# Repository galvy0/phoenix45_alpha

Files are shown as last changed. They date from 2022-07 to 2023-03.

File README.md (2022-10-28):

# Phoenix45 Alpha Stagger PCB
Alpha stagger version of Phoenix45.  
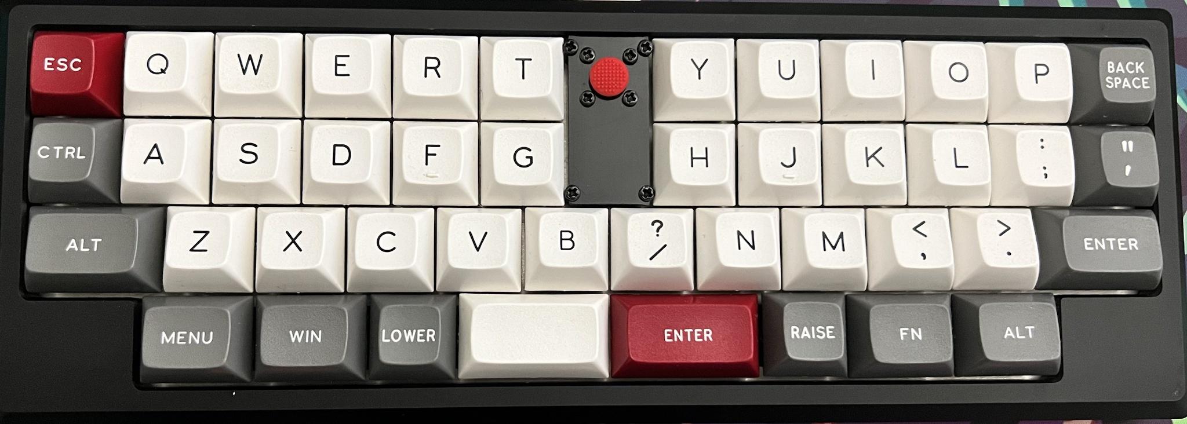
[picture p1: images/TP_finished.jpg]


## PCB
### Layout Options
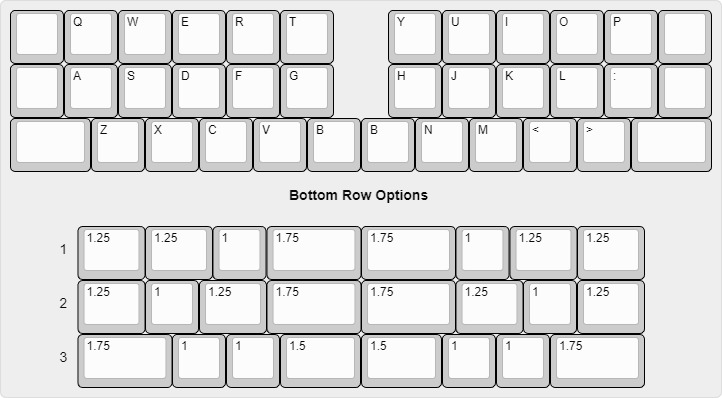
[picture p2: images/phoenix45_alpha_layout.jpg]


## Middle Column Options
The middle column can be configured with either an OLED or a trackpoint module.  

### Middle Column Cover
Either case, I provide the files for a cover along with plate option to mount the cover.  
Using the cover would help fill/cover up the space between the plate and the top of the case and make the middle column look more flush with the top of the case (a.k.a it's just for aesthetics).  
To use the cover, you need M2 screws and standoffs - I find ~6 mm is a good length for the standoffs, though 7 mm also works well and gives enough space for the trackpoint module.  

### Trackpoint module
The only TP module compatible with this is the two-piece module found in ThinkPad T440/T450/T460/T470/T480, P52s, X240, X250, X260 X270 (according to https://deskthority.net/wiki/TrackPoint_Hardware).  
I just bought some replacement T440/T450 keyboards from Ebay and scavanged the TP modules.  
Steps (Very rough - I will try to take some photos for better instructions next time I build this):  
1. Unscrew the casing for the TP module.
2. Install a TP cover. This can be done later.    
Depending on the thickness of the cover, you may want to have hex nuts between the module and the cover so the TP sticks out as little as possible (mainly for aesthetics).  
3. Desolder all the lines and reconnect them using flexible wires so you can readjust the position of the TP module with the TP PCB.  
4. Refer to the pinouts from Deskthority to connect the pins on the TP PCB to the keyboard PCB.  
 
5. With the plate standoffs pre-installed, position the TP PCB slanted through the middle column.  
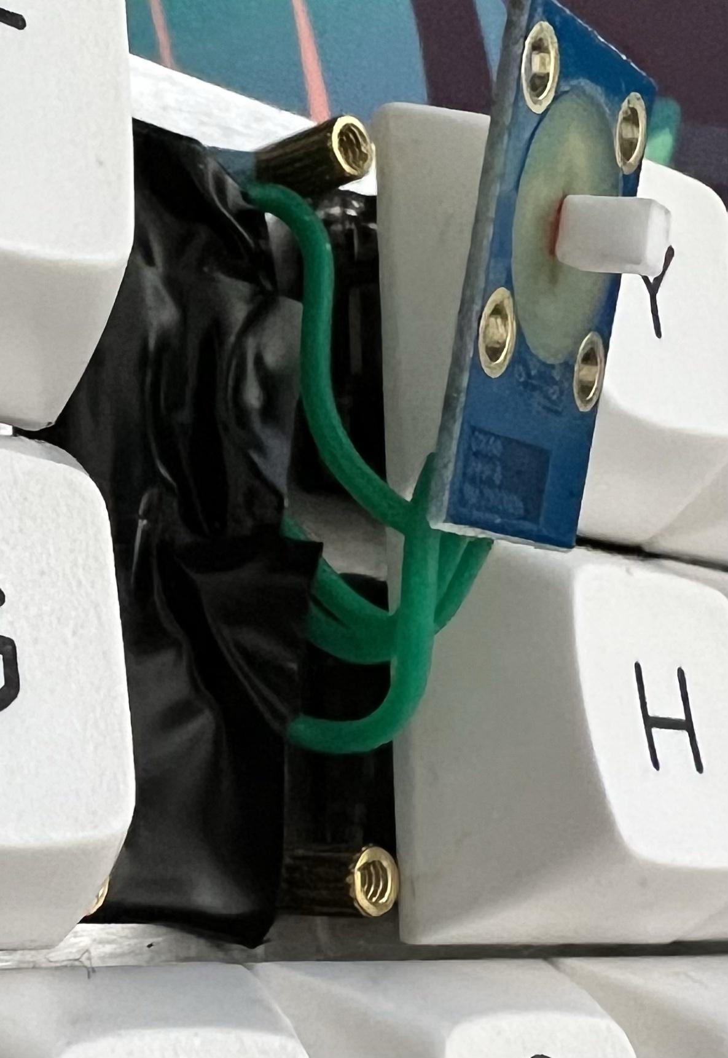
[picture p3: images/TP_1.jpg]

6. Install the TP cover to the plate.  
After all is done, it would look something like this: 
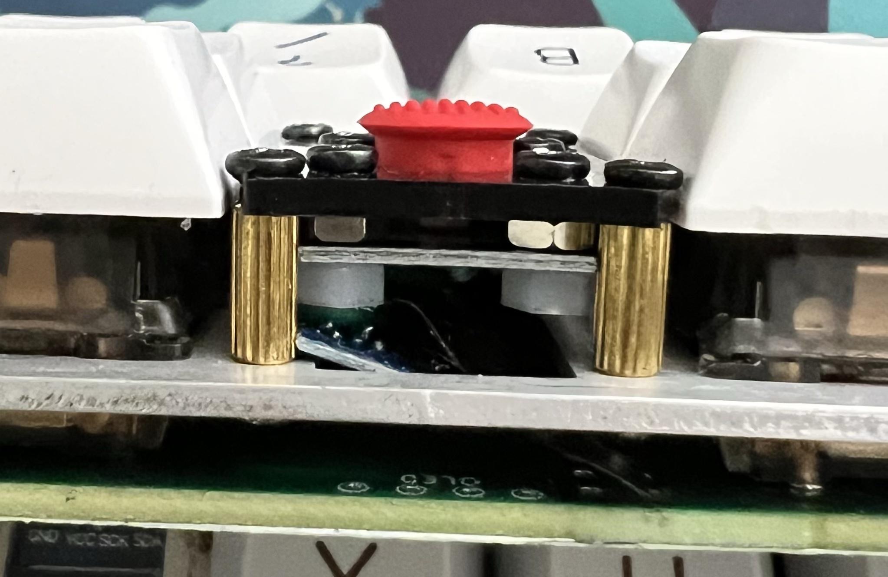
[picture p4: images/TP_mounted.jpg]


## QMK Firmware
https://github.com/galvy0/qmk_firmware/tree/galvy/keyboards/galvy/jd45_alpha

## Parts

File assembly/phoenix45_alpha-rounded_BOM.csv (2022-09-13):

Id | Designator | Package | Quantity | Designation | Supplier and ref
1 | K_SPACE30,K_SPACE31,K_SPACE38,K_SPACE22,K_SPACE11,K_SPACE39,K_SPACE1,K_SPACE46,K_SPACE50,K_SPACE12,K_SPACE10,K_SPACE37,K_SPACE24,K_SPACE9,K_SPACE15,K_SPACE55,K_SPACE51,K_SPACE17,K_SPACE34,K_SPACE41,K_SPACE16,K_SPACE25,K_SPACE59,K_SPACE21,K_SPACE28,K_SPACE35,K_SPACE6,K_SPACE14,K_SPACE54,K_SPACE3,K_SPACE58,K_SPACE19,K_SPACE13,K_SPACE5,K_SPACE26,K_SPACE36,K_SPACE18,K_SPACE8,K_SPACE27,K_SPACE32,K_SPACE29,K_SPACE23,K_SPACE2,K_SPACE4 | MXOnly-1U-NoLED | 44 | KEYSW
2 | K_SPACE40,K_SPACE42,K_SPACE57,K_SPACE33,K_SPACE48,K_SPACE47,K_SPACE45,K_SPACE60 | MXOnly-1.25U-NoLED | 8 | KEYSW
3 | K_SPACE56,K_SPACE49,K_SPACE43,K_SPACE44 | MXOnly-1.75U-NoLED | 4 | KEYSW
4 | SW3 | RotaryEncoder_Alps_EC11E-Switch_Vertical_H20mm | 1 | RotaryEncoder_Switch
5 | SW2,SW1 | SW_SPST_SKQG_WithoutStem | 2 | SW_PUSH
6 | TP1 | TestPoint_THTPad_1.0x1.0mm_Drill0.5mm | 1 | TPCLK
7 | TP3 | TestPoint_THTPad_1.0x1.0mm_Drill0.5mm | 1 | TPGND
8 | TP2 | TestPoint_THTPad_1.0x1.0mm_Drill0.5mm | 1 | TPVCC
9 | TP5 | TestPoint_THTPad_1.0x1.0mm_Drill0.5mm | 1 | TPRST
10 | K_SPACE52,K_SPACE7,K_SPACE20,K_SPACE53 | MXOnly-1.5U-NoLED | 4 | KEYSW
11 | TP4 | TestPoint_THTPad_1.0x1.0mm_Drill0.5mm | 1 | TPDATA
12 | OL1 | OLED_v2 | 1 | OLED
13 | D_SPACE29,D_SPACE30,D_SPACE44,D_SPACE26,D_SPACE22,D_SPACE16,D_SPACE13,D_SPACE43,D_SPACE45,D_SPACE25,D_SPACE28,D_SPACE39,D_SPACE2,D_SPACE14,D_SPACE46,D_SPACE11,D_SPACE4,D_SPACE8,D_SPACE19,D_SPACE42,D_SPACE12,D_SPACE23,D_SPACE34,D_SPACE36,D_SPACE32,D_SPACE3,D_SPACE24,D_SPACE31,D_SPACE37,D_SPACE38,D_SPACE10,D_SPACE6,D_SPACE5,D_SPACE27,D_SPACE41,D_SPACE35,D_SPACE21,D_SPACE18,D_SPACE9,D_SPACE17,D_SPACE15,D_SPACE1,D_SPACE40,D_SPACE47 | D_SOD-123 | 44 | D
14 | UR2,UR1 | R_0805_2012Metric_Pad1.20x1.40mm_HandSolder | 2 | 22
15 | X1 | Crystal_SMD_3225-4Pin_3.2x2.5mm_HandSoldering | 1 | Crystal_GND24_Small
16 | C0 | C_0805_2012Metric_Pad1.18x1.45mm_HandSolder | 1 | 4.7uF
17 | C2,C4,C5,C3 | C_0805_2012Metric_Pad1.18x1.45mm_HandSolder | 4 | 0.1uf
18 | R2,R1 | R_0805_2012Metric_Pad1.20x1.40mm_HandSolder | 2 | 10k
19 | U2 | QFN-44-1EP_7x7mm_P0.5mm_EP5.2x5.2mm_ThermalVias | 1 | ATmega32U4-M
20 | C8,C7 | C_0805_2012Metric_Pad1.18x1.45mm_HandSolder | 2 | 22p
21 | C6 | C_0805_2012Metric_Pad1.18x1.45mm_HandSolder | 1 | 1uf
22 | UR3 | R_0805_2012Metric_Pad1.20x1.40mm_HandSolder | 1 | 1M
23 | C1 | C_0805_2012Metric_Pad1.18x1.45mm_HandSolder | 1 | 10uF
24 | UR4,UR5 | R_0805_2012Metric_Pad1.20x1.40mm_HandSolder | 2 | 5.1k
25 | C9 | C_0805_2012Metric_Pad1.18x1.45mm_HandSolder | 1 | 2.2uF
26 | UR8 | R_0805_2012Metric_Pad1.20x1.40mm_HandSolder | 1 | 100k
27 | USB1 | HRO-TYPE-C-31-M-12-HandSoldering | 1 | HRO-TYPE-C-31-M-12
28 | J1 | IDC-Header_2x03_P2.54mm_Vertical | 1 | AVR-ISP-6
29 | U1 | SOT-23-6_Handsoldering | 1 | SRV05-4
30 | UR7,UR6 | R_0805_2012Metric_Pad1.20x1.40mm_HandSolder | 2 | 4.7k
31 | F1 | Fuse_1206_3216Metric_Pad1.42x1.75mm_HandSolder | 1 | Polyfuse_Small

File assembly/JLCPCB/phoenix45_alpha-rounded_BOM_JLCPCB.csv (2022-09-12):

Comment | Designator | Footprint | JLCPCB Part (optional)
1N4148W | D_SPACE29,D_SPACE30,D_SPACE44,D_SPACE26,D_SPACE22,D_SPACE16,D_SPACE13,D_SPACE43,D_SPACE45,D_SPACE25,D_SPACE28,D_SPACE39,D_SPACE2,D_SPACE14,D_SPACE46,D_SPACE11,D_SPACE4,D_SPACE8,D_SPACE19,D_SPACE42,D_SPACE12,D_SPACE23,D_SPACE34,D_SPACE36,D_SPACE32,D_SPACE3,D_SPACE24,D_SPACE31,D_SPACE37,D_SPACE38,D_SPACE10,D_SPACE6,D_SPACE5,D_SPACE27,D_SPACE41,D_SPACE35,D_SPACE21,D_SPACE18,D_SPACE9,D_SPACE17,D_SPACE15,D_SPACE1,D_SPACE40,D_SPACE47 | SOD-123 | C81598
22 | UR2,UR1 | R0805 | C17561
16 Mhz Crystal | X1 | SMD-3225_4P | C13738
4.7uF | C0 | C0805 | C1779
0.1uF | C2,C4,C5,C3 | C0805 | C49678
10k | R2,R1 | R0805 | C17414
ATMEGA32U4 | U2 | VQFN-44_EP_7.0x7.0x0.5P | C112161
22pF | C8,C7 | C0805 | C1804
1uF | C6 | C0805 | C91185
1M | UR3 | R0805 | C17514
10uF | C1 | C0805 | C15850
5.1k | UR4,UR5 | R0805 | C27834
2.2uF | C9 | C0805 | C49217
100k | UR8 | R0805 | C149504
HRO-TYPE-C-31-M-12 | USB1 | TYPE-C-31-M-12 | C165948
SRV05-4 | U1 | SOT-23-6 | C85364
4.7k | UR7,UR6 | R0805 | C17673
1206L035/16YR | F1 | F1206 | C126817

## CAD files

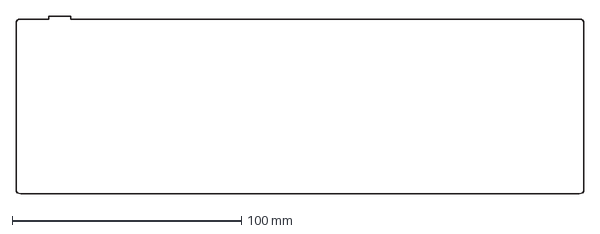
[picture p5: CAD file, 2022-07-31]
pheonix45_edge_cuts.dxf
247.7 x 77.5 mm

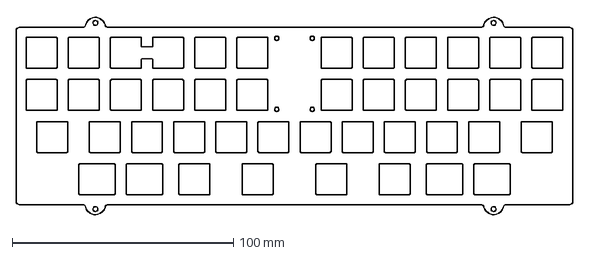
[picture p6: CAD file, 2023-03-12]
plate/phoenix45_alpha_plate_premium_galvy_final.dxf
251.6 x 90.2 mm

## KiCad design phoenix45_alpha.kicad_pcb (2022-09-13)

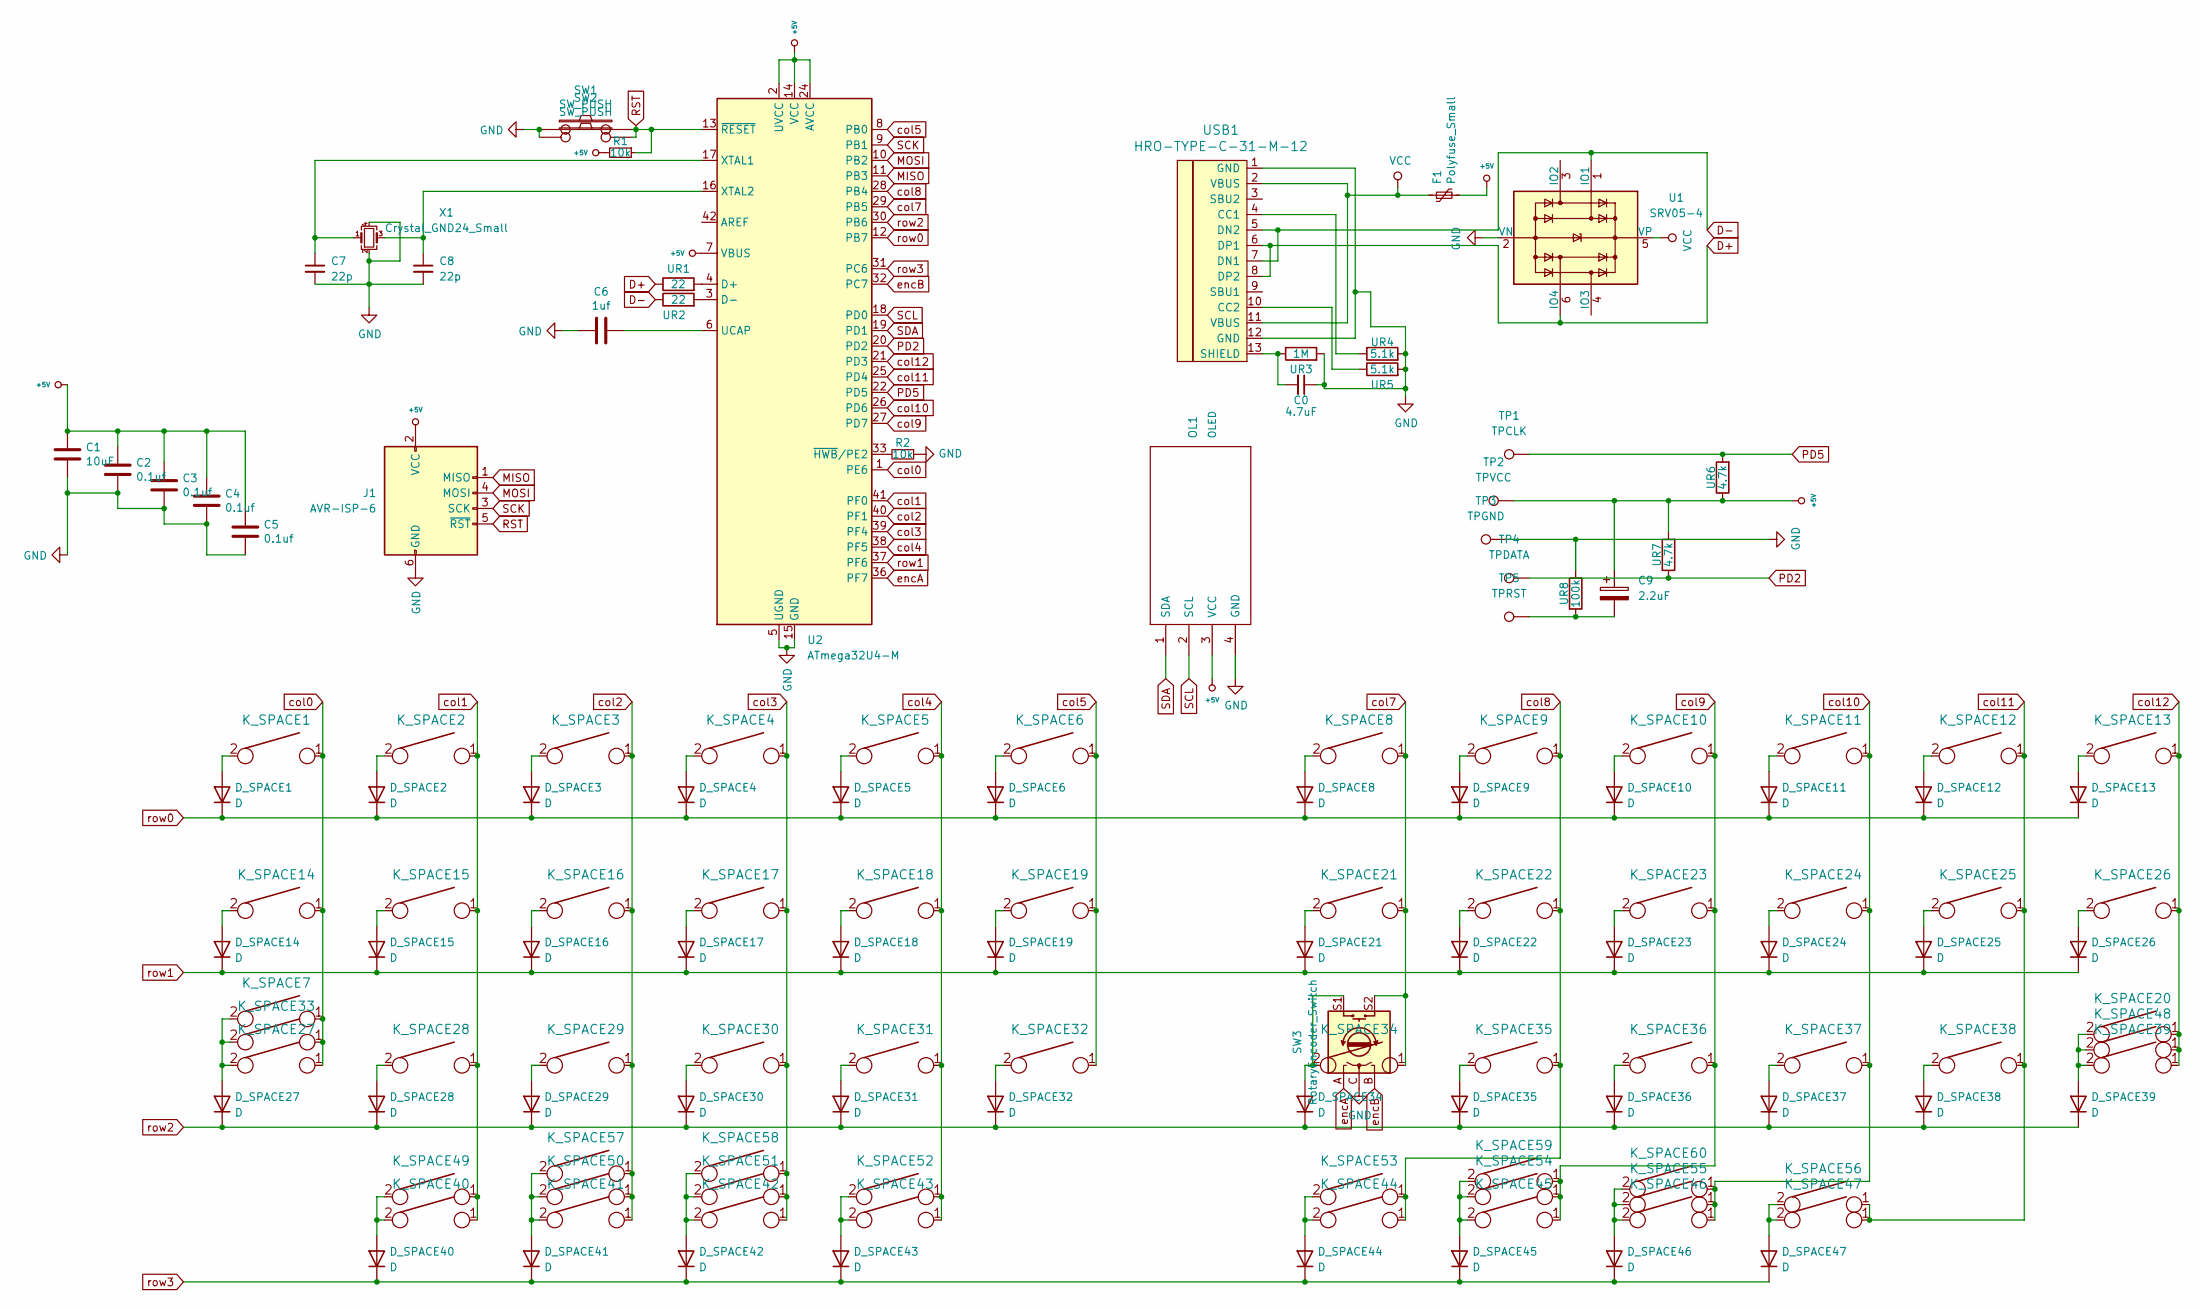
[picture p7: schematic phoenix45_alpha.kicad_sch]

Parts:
C0: 4.7uF; C_0805_2012Metric_Pad1.18x1.45mm_HandSolder
C1: 10uF; C_0805_2012Metric_Pad1.18x1.45mm_HandSolder
C2, C3, C4, C5: 0.1uf; C_0805_2012Metric_Pad1.18x1.45mm_HandSolder
C6: 1uf; C_0805_2012Metric_Pad1.18x1.45mm_HandSolder
C7, C8: 22p; C_0805_2012Metric_Pad1.18x1.45mm_HandSolder
C9: 2.2uF; C_0805_2012Metric_Pad1.18x1.45mm_HandSolder
D_SPACE1, D_SPACE2, D_SPACE3, D_SPACE4, D_SPACE5, D_SPACE6, D_SPACE8, D_SPACE9, D_SPACE10, D_SPACE11, D_SPACE12, D_SPACE13, D_SPACE14, D_SPACE15, D_SPACE16, D_SPACE17, D_SPACE18, D_SPACE19, D_SPACE21, D_SPACE22, D_SPACE23, D_SPACE24, D_SPACE25, D_SPACE26, D_SPACE27, D_SPACE28, D_SPACE29, D_SPACE30, D_SPACE31, D_SPACE32, D_SPACE34, D_SPACE35, D_SPACE36, D_SPACE37, D_SPACE38, D_SPACE39, D_SPACE40, D_SPACE41, D_SPACE42, D_SPACE43, D_SPACE44, D_SPACE45, D_SPACE46, D_SPACE47: D; D_SOD-123
F1: Polyfuse_Small; Fuse_1206_3216Metric_Pad1.42x1.75mm_HandSolder
J1: AVR-ISP-6; IDC-Header_2x03_P2.54mm_Vertical
K_SPACE1, K_SPACE2, K_SPACE3, K_SPACE4, K_SPACE5, K_SPACE6, K_SPACE8, K_SPACE9, K_SPACE10, K_SPACE11, K_SPACE12, K_SPACE13, K_SPACE14, K_SPACE15, K_SPACE16, K_SPACE17, K_SPACE18, K_SPACE19, K_SPACE21, K_SPACE22, K_SPACE23, K_SPACE24, K_SPACE25, K_SPACE26, K_SPACE27, K_SPACE28, K_SPACE29, K_SPACE30, K_SPACE31, K_SPACE32, K_SPACE34, K_SPACE35, K_SPACE36, K_SPACE37, K_SPACE38, K_SPACE39, K_SPACE41, K_SPACE46, K_SPACE50, K_SPACE51, K_SPACE54, K_SPACE55, K_SPACE58, K_SPACE59: KEYSW; MXOnly-1U-NoLED
K_SPACE7, K_SPACE20, K_SPACE52, K_SPACE53: KEYSW; MXOnly-1.5U-NoLED
K_SPACE33, K_SPACE40, K_SPACE42, K_SPACE45, K_SPACE47, K_SPACE48, K_SPACE57, K_SPACE60: KEYSW; MXOnly-1.25U-NoLED
K_SPACE43, K_SPACE44, K_SPACE49, K_SPACE56: KEYSW; MXOnly-1.75U-NoLED
OL1: OLED; OLED_v2
R1, R2: 10k; R_0805_2012Metric_Pad1.20x1.40mm_HandSolder
SW1, SW2: SW_PUSH; SW_SPST_SKQG_WithoutStem
SW3: RotaryEncoder_Switch; RotaryEncoder_Alps_EC11E-Switch_Vertical_H20mm
TP1: TPCLK; TestPoint_THTPad_1.0x1.0mm_Drill0.5mm
TP2: TPVCC; TestPoint_THTPad_1.0x1.0mm_Drill0.5mm
TP3: TPGND; TestPoint_THTPad_1.0x1.0mm_Drill0.5mm
TP4: TPDATA; TestPoint_THTPad_1.0x1.0mm_Drill0.5mm
TP5: TPRST; TestPoint_THTPad_1.0x1.0mm_Drill0.5mm
U1: SRV05-4; SOT-23-6_Handsoldering
U2: ATmega32U4-M; QFN-44-1EP_7x7mm_P0.5mm_EP5.2x5.2mm_ThermalVias
UR1, UR2: 22; R_0805_2012Metric_Pad1.20x1.40mm_HandSolder
UR3: 1M; R_0805_2012Metric_Pad1.20x1.40mm_HandSolder
UR4, UR5: 5.1k; R_0805_2012Metric_Pad1.20x1.40mm_HandSolder
UR6, UR7: 4.7k; R_0805_2012Metric_Pad1.20x1.40mm_HandSolder
UR8: 100k; R_0805_2012Metric_Pad1.20x1.40mm_HandSolder
USB1: HRO-TYPE-C-31-M-12; HRO-TYPE-C-31-M-12-HandSoldering
X1: Crystal_GND24_Small; Crystal_SMD_3225-4Pin_3.2x2.5mm_HandSoldering

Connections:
+5V: C1.1, C2.1, C3.1, C4.1, C5.1, C9.1, F1.2, J1.2 (VCC), OL1.3 (VCC), R1.2, TP2.1, U2.2 (UVCC), U2.7 (VBUS), U2.14 (VCC), U2.24 (AVCC), U2.34 (VCC), U2.44 (AVCC), UR6.1, UR7.2
D+: U1.6 (IO4), UR2.1, USB1.6 (DP1), USB1.8 (DP2)
D-: U1.1 (IO1), UR1.1, USB1.5 (DN2), USB1.7 (DN1)
GND: C0.1, C1.2, C2.2, C3.2, C4.2, C5.2, C6.2, C7.2, C8.2, J1.6 (GND), OL1.4 (GND), R2.1, SW1.1, SW2.1, SW3.C, TP3.1, U1.2 (VN), U2.5 (UGND), U2.15 (GND), U2.23 (GND), U2.35 (GND), U2.43 (GND), U2.45 (GND), UR3.2, UR4.2, UR5.2, UR8.2, USB1.1 (GND), USB1.12 (GND), X1.2, X1.4
MISO: J1.1 (MISO), U2.11 (PB3)
MOSI: J1.4 (MOSI), U2.10 (PB2)
unnamed: C0.2, UR3.1, USB1.13 (SHIELD)
unnamed: C6.1, U2.6 (UCAP)
unnamed: C7.1, U2.17 (XTAL1), X1.1
unnamed: C8.1, U2.16 (XTAL2), X1.3
unnamed: C9.2, TP5.1, UR8.1
unnamed: D_SPACE1.2 (A), K_SPACE1.2
unnamed: D_SPACE2.2 (A), K_SPACE2.2
unnamed: D_SPACE3.2 (A), K_SPACE3.2
unnamed: D_SPACE4.2 (A), K_SPACE4.2
unnamed: D_SPACE5.2 (A), K_SPACE5.2
unnamed: D_SPACE6.2 (A), K_SPACE6.2
unnamed: D_SPACE8.2 (A), K_SPACE8.2
unnamed: D_SPACE9.2 (A), K_SPACE9.2
unnamed: D_SPACE10.2 (A), K_SPACE10.2
unnamed: D_SPACE11.2 (A), K_SPACE11.2
unnamed: D_SPACE12.2 (A), K_SPACE12.2
unnamed: D_SPACE13.2 (A), K_SPACE13.2
unnamed: D_SPACE14.2 (A), K_SPACE14.2
unnamed: D_SPACE15.2 (A), K_SPACE15.2
unnamed: D_SPACE16.2 (A), K_SPACE16.2
unnamed: D_SPACE17.2 (A), K_SPACE17.2
unnamed: D_SPACE18.2 (A), K_SPACE18.2
unnamed: D_SPACE19.2 (A), K_SPACE19.2
unnamed: D_SPACE21.2 (A), K_SPACE21.2
unnamed: D_SPACE22.2 (A), K_SPACE22.2
unnamed: D_SPACE23.2 (A), K_SPACE23.2
unnamed: D_SPACE24.2 (A), K_SPACE24.2
unnamed: D_SPACE25.2 (A), K_SPACE25.2
unnamed: D_SPACE26.2 (A), K_SPACE26.2
unnamed: D_SPACE27.2 (A), K_SPACE7.2, K_SPACE27.2, K_SPACE33.2
unnamed: D_SPACE28.2 (A), K_SPACE28.2
unnamed: D_SPACE29.2 (A), K_SPACE29.2
unnamed: D_SPACE30.2 (A), K_SPACE30.2
unnamed: D_SPACE31.2 (A), K_SPACE31.2
unnamed: D_SPACE32.2 (A), K_SPACE32.2
unnamed: D_SPACE34.2 (A), K_SPACE34.2, SW3.S1
unnamed: D_SPACE35.2 (A), K_SPACE35.2
unnamed: D_SPACE36.2 (A), K_SPACE36.2
unnamed: D_SPACE37.2 (A), K_SPACE37.2
unnamed: D_SPACE38.2 (A), K_SPACE38.2
unnamed: D_SPACE39.2 (A), K_SPACE20.2, K_SPACE39.2, K_SPACE48.2
unnamed: D_SPACE40.2 (A), K_SPACE40.2, K_SPACE49.2
unnamed: D_SPACE41.2 (A), K_SPACE41.2, K_SPACE50.2, K_SPACE57.2
unnamed: D_SPACE42.2 (A), K_SPACE42.2, K_SPACE51.2, K_SPACE58.2
unnamed: D_SPACE43.2 (A), K_SPACE43.2, K_SPACE52.2
unnamed: D_SPACE44.2 (A), K_SPACE44.2, K_SPACE53.2
unnamed: D_SPACE45.2 (A), K_SPACE45.2, K_SPACE54.2, K_SPACE59.2
unnamed: D_SPACE46.2 (A), K_SPACE46.2, K_SPACE55.2, K_SPACE60.2
unnamed: D_SPACE47.2 (A), K_SPACE47.2, K_SPACE56.2
unnamed: R2.2, U2.33 (~HWB/PE2)
unnamed: U2.3 (D-), UR1.2
unnamed: U2.4 (D+), UR2.2
unnamed: UR4.1, USB1.4 (CC1)
unnamed: UR5.1, USB1.10 (CC2)
PD2: TP4.1, U2.20 (PD2), UR7.1
PD5: TP1.1, U2.22 (PD5), UR6.2
RST: J1.5 (~RST), R1.1, SW1.2, SW2.2, U2.13 (~RESET)
SCK: J1.3 (SCK), U2.9 (PB1)
SCL: OL1.2 (SCL), U2.18 (PD0)
SDA: OL1.1 (SDA), U2.19 (PD1)
VCC: F1.1, U1.5 (VP), USB1.2 (VBUS), USB1.11 (VBUS)
col0: K_SPACE1.1, K_SPACE7.1, K_SPACE14.1, K_SPACE27.1, K_SPACE33.1, U2.1 (PE6)
col1: K_SPACE2.1, K_SPACE15.1, K_SPACE28.1, K_SPACE40.1, K_SPACE49.1, U2.41 (PF0)
col2: K_SPACE3.1, K_SPACE16.1, K_SPACE29.1, K_SPACE41.1, K_SPACE50.1, K_SPACE57.1, U2.40 (PF1)
col3: K_SPACE4.1, K_SPACE17.1, K_SPACE30.1, K_SPACE42.1, K_SPACE51.1, K_SPACE58.1, U2.39 (PF4)
col4: K_SPACE5.1, K_SPACE18.1, K_SPACE31.1, K_SPACE43.1, K_SPACE52.1, U2.38 (PF5)
col5: K_SPACE6.1, K_SPACE19.1, K_SPACE32.1, U2.8 (PB0)
col7: K_SPACE8.1, K_SPACE21.1, K_SPACE34.1, SW3.S2, U2.29 (PB5)
col8: K_SPACE9.1, K_SPACE22.1, K_SPACE35.1, K_SPACE44.1, K_SPACE53.1, U2.28 (PB4)
col9: K_SPACE10.1, K_SPACE23.1, K_SPACE36.1, K_SPACE45.1, K_SPACE54.1, K_SPACE59.1, U2.27 (PD7)
col10: K_SPACE11.1, K_SPACE24.1, K_SPACE37.1, K_SPACE46.1, K_SPACE55.1, K_SPACE60.1, U2.26 (PD6)
col11: K_SPACE12.1, K_SPACE25.1, K_SPACE38.1, K_SPACE47.1, K_SPACE56.1, U2.25 (PD4)
col12: K_SPACE13.1, K_SPACE20.1, K_SPACE26.1, K_SPACE39.1, K_SPACE48.1, U2.21 (PD3)
encA: SW3.A, U2.36 (PF7)
encB: SW3.B, U2.32 (PC7)
row0: D_SPACE1.1 (K), D_SPACE2.1 (K), D_SPACE3.1 (K), D_SPACE4.1 (K), D_SPACE5.1 (K), D_SPACE6.1 (K), D_SPACE8.1 (K), D_SPACE9.1 (K), D_SPACE10.1 (K), D_SPACE11.1 (K), D_SPACE12.1 (K), D_SPACE13.1 (K), U2.12 (PB7)
row1: D_SPACE14.1 (K), D_SPACE15.1 (K), D_SPACE16.1 (K), D_SPACE17.1 (K), D_SPACE18.1 (K), D_SPACE19.1 (K), D_SPACE21.1 (K), D_SPACE22.1 (K), D_SPACE23.1 (K), D_SPACE24.1 (K), D_SPACE25.1 (K), D_SPACE26.1 (K), U2.37 (PF6)
row2: D_SPACE27.1 (K), D_SPACE28.1 (K), D_SPACE29.1 (K), D_SPACE30.1 (K), D_SPACE31.1 (K), D_SPACE32.1 (K), D_SPACE34.1 (K), D_SPACE35.1 (K), D_SPACE36.1 (K), D_SPACE37.1 (K), D_SPACE38.1 (K), D_SPACE39.1 (K), U2.30 (PB6)
row3: D_SPACE40.1 (K), D_SPACE41.1 (K), D_SPACE42.1 (K), D_SPACE43.1 (K), D_SPACE44.1 (K), D_SPACE45.1 (K), D_SPACE46.1 (K), D_SPACE47.1 (K), U2.31 (PC6)

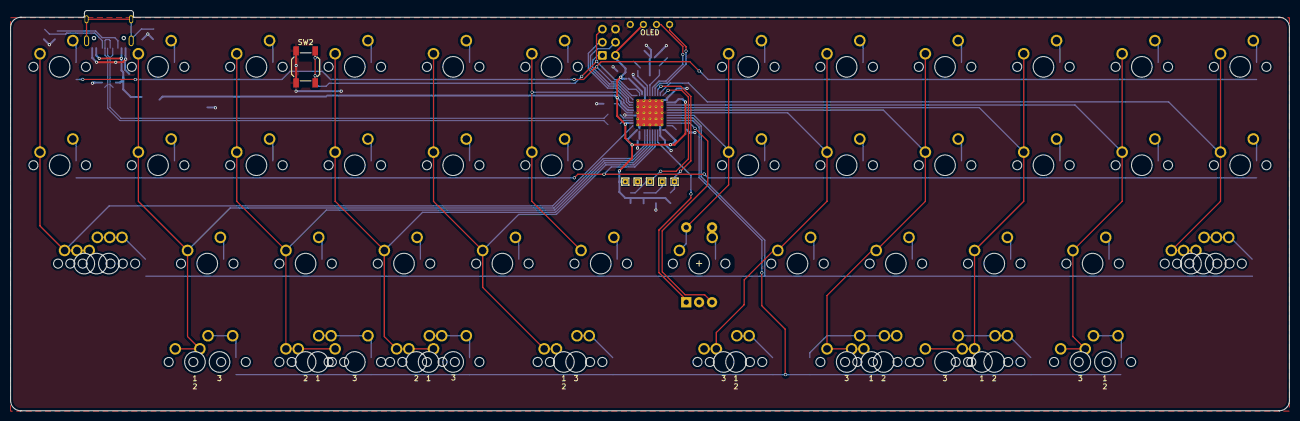
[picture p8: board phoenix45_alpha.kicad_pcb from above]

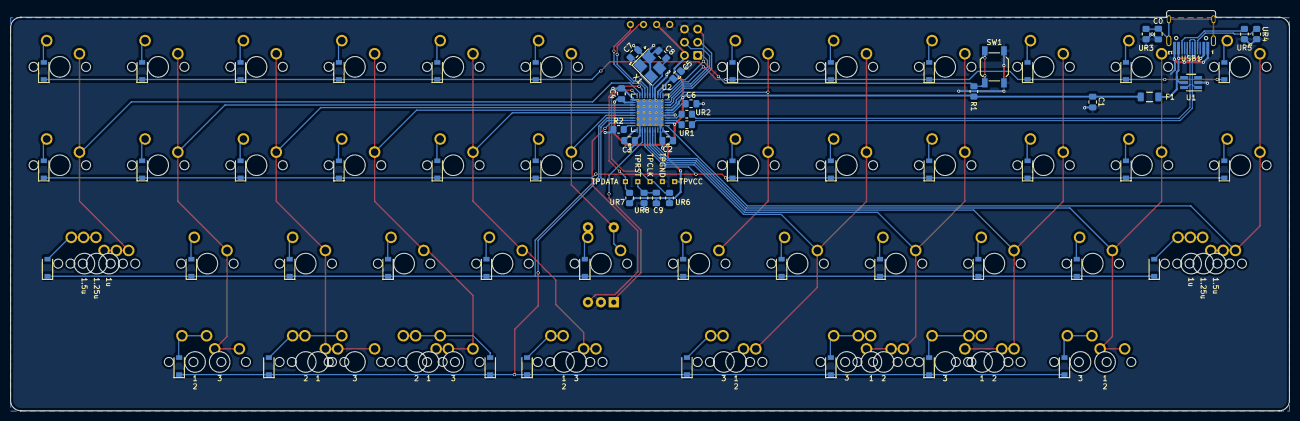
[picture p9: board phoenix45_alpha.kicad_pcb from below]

Board: 2 copper layers, 247.7 x 77.5 mm, 139 parts (71 on the bottom side), 85 nets.

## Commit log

2022-07-31 change name to alpha
    [Phoenix_Ortho-Edge_Cuts.dxf, pheonix45_edge_cuts.dxf, phoenix45_alpha.kicad_pcb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]
2022-08-01 added avr
    [phoenix45_alpha-rounded.kicad_pcb, phoenix45_alpha.kicad_pcb, phoenix45_alpha.kicad_sch]
2022-08-01 v1 finished
    [phoenix45_alpha-rounded-B_Cu.gbl, phoenix45_alpha-rounded-B_Mask.gbs, phoenix45_alpha-rounded-B_Silkscreen.gbo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]
2022-08-07 qfn + tqfp
    [phoenix45_alpha-rounded.kicad_pcb, phoenix45_alpha.kicad_pcb, phoenix45_alpha.kicad_sch]
2022-08-08 Move TP connectors to front
    [phoenix45_alpha-rounded.kicad_pcb, phoenix45_alpha.kicad_pcb]
2022-08-10 round tracks
    [phoenix45_alpha-rounded.kicad_pcb]
2022-09-10 go back to MX
    [phoenix45_alpha.kicad_pcb, phoenix45_alpha.kicad_sch]
2022-09-11 improve trackpoint compatibility; multiple bottom rows, final touch up
    [phoenix45_alpha.kicad_pcb, phoenix45_alpha.kicad_sch]
2022-09-12 assembly prep
    [phoenix45_alpha-rounded-B_Cu.gbl, phoenix45_alpha-rounded-B_Mask.gbs, phoenix45_alpha-rounded-B_Silkscreen.gbo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]
2022-09-12 atmega32u4-MU only
    [phoenix45_alpha-rounded-B_Cu.gbl, phoenix45_alpha-rounded-B_Mask.gbs, phoenix45_alpha-rounded-B_Silkscreen.gbo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]
2022-09-13 minor adjustments
    [phoenix45_alpha.kicad_pcb]
